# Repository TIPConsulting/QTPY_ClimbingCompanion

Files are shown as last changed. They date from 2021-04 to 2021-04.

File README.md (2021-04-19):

# QTPY Climbing Companion

Signaling device for climbers to communicate when voice commands or hand signs are not feasible.  This is a discreet helmet augmentation that adds simple radio signaling to your existing helmet.  Climbing Companion uses small touch sensors and vibrators to send left hand or right hand signals.  These can be combined to communicate arbitrary commands to your partner.  The nRF24+ radio module can reach up 100m, so you'll never have to worry about signaling again on long routes.

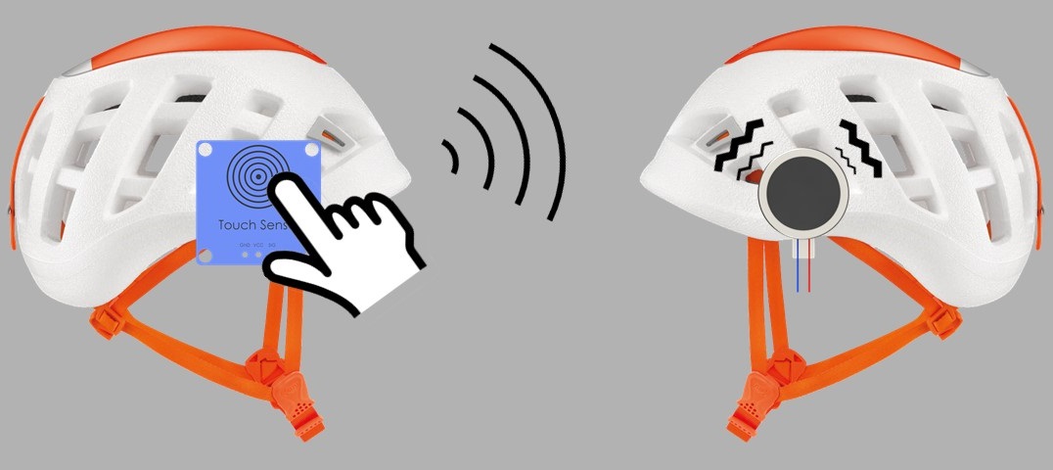
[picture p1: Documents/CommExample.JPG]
CommExample


## Inspiration

Climbing Companion is inspired by own experiences climbing across Colorado.  Its common to find yourself climbing near loud rivers or busy roads where its difficult for belayers and climbers to hear each other.  Furthermore, many routes are shaped such that partners can't see each other after the first 40ft of climbing.  When these obstacles intersect, belayers are forced to make critical safety decisions based on intuition.  Many climbers have died due to such communication failures.

Climbing Companion provides a stable platform for partners to signal each other when primary methods are unreliable.  Some climbers elect to carry 2-way hand radios, but these can be bulky and present a new safety risk if they are dropped or they could injure the climber during a fall.  Climbing Companion opts for a more streamlined approach than conventional radios.  By only supporting a small set of signaling features, we are able to squeeze our hardware into a tiny package and integrate it directly into a helmet.  This means that the device is also right where it needs to be - it won't shift around, it won't fall off a harness, and it won't get in your way.

The goal is not to replace all voice commands or hand signals, but rather supplement them during safety critical operations like setting anchors or cleaning routes.  The following image shows a scenario in which Climbing Companion would be ideal - the belayer is not visible and a fast river drowns out any voice commands.  Our radio module would allow the climber to signal when he sets his anchor or needs a rest.

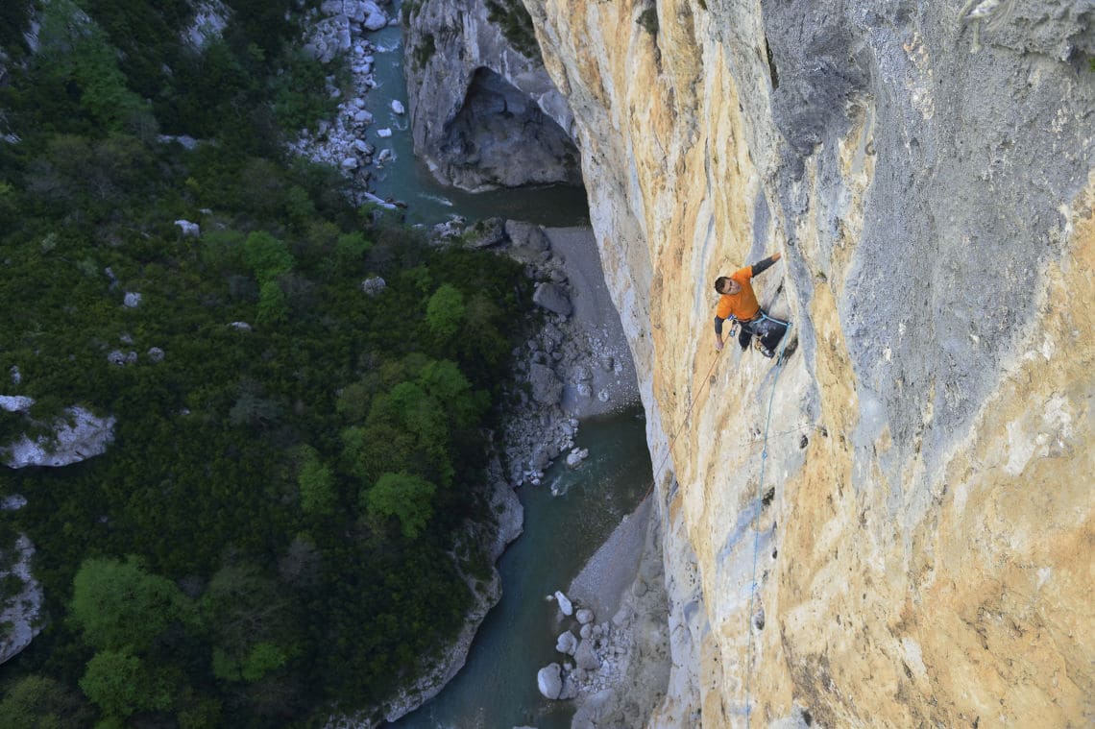
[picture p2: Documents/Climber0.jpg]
Climber


## Hardware

- 2x [QT Py Microcontroller](https://www.adafruit.com/product/4600)
- 2x [RF24 Radio Modules](https://www.amazon.com/Makerfire-Arduino-NRF24L01-Wireless-Transceiver/dp/B00O9O868G)
- 2x 150mAH Lipo Battery
- 2x Slide Switch
- 4x [Vibrator Disc](https://www.amazon.com/tatoko-12000RPM-Wired-Phone-Vibration/dp/B07L5V5GYG/)
- 4x Touch Sensor / Conductive Strips

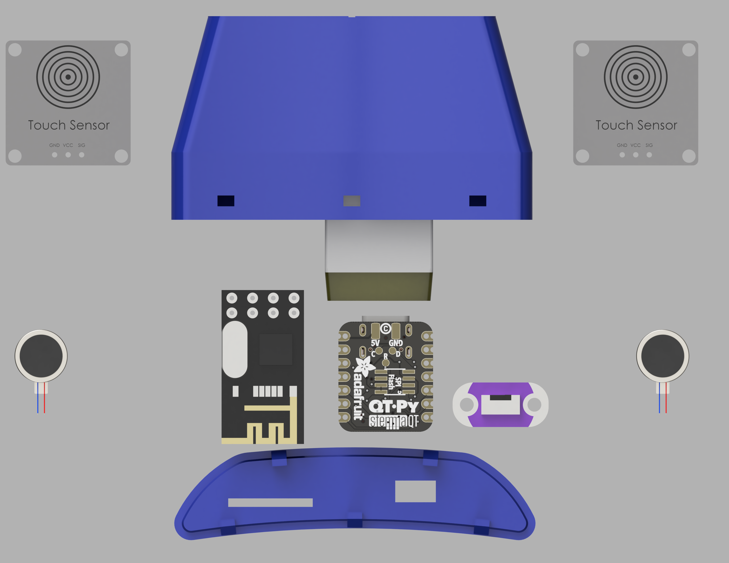
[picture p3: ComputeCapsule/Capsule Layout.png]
Component Layout


## Design

From the very outset, we knew that Climbing Companion would have to prioritize form factor and energy use over features.  We chose small, low power components to meet the functional requirements and nothing more.  That allows us pack our device into a tiny case - its so small that it can fit it a helmet vent!  Small parts also means low weight; the compute capsule _weighs 24g_, that's less than a locking carabiner!  You won't even notice that it's there unless your partner is signaling to you.  And our long battery life means that your partner can signal all day long, no matter how early you hit the crag.

We designed and printed an enclosure for a hemlet we have on-hand, but similar cases could be made a varity of helmets, allowing Climbing Companion to seamlessly integrate with your existing gear.

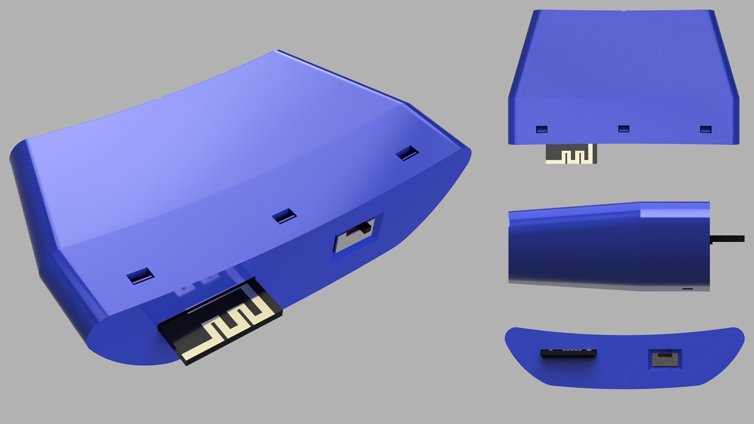
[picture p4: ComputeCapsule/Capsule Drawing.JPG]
Capsule Render


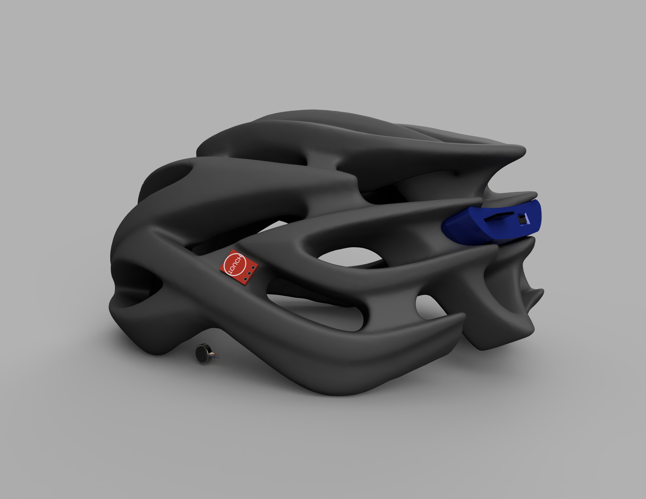
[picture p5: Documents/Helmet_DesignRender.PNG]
Helmet Render


## Build Process

Component Explosion

Helmet Explosion

### [3D STL Viewer](https://a360.co/2RFK8qV)

### Electronics

The electronics are not terribly difficult to assemble. Simply follow the standard nRF24+ wiring diagram to connect the RF module to the QT Py controller.  The connecting wires should be short so the devices can be compacted together in the case.  After connected the RF, attach leads to the QT Py for the vibrators and touch sensors.  These will need to be longer so they can extend outside of the case.  Finish off by adding a battery connector and power switch.

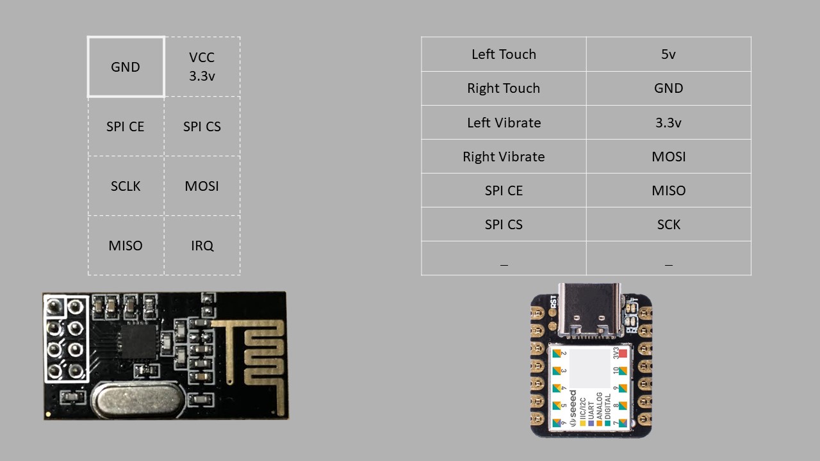
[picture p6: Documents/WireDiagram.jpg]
Wire Diagram
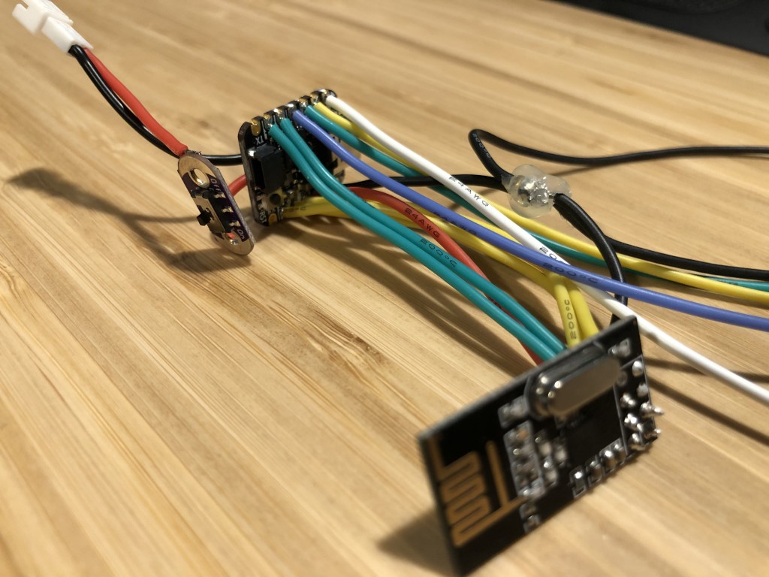
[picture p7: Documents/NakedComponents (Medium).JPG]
Electronics
 

### Compute Capsule

For the best integration possible, each compute capsule is designed to fit a specific helmet and vent.  It is critical to get a capsule that perfectly fits the helmet vent and provides enough room for the components.  It took half a dozen prototypes before we were satisfied with the fit and finish of our capsule.

### Compute Capsule Assembly

Once the components are soldered together and the case fit is perfected, the electronics will need to be inserted into the case.  We designed holes into the back of our capsule to allow vibrator and sensor wires to pass through unobtrusively.  We passed these wires through the shell first and used them to gently pull everything into place.  Only after this step should the final components be added.  If you were to add the vibrators and sensors too early, you would not be able to properly assemble the device.

1. Assemble the electronics into the compute capsule.  Do not seal the capsule yet

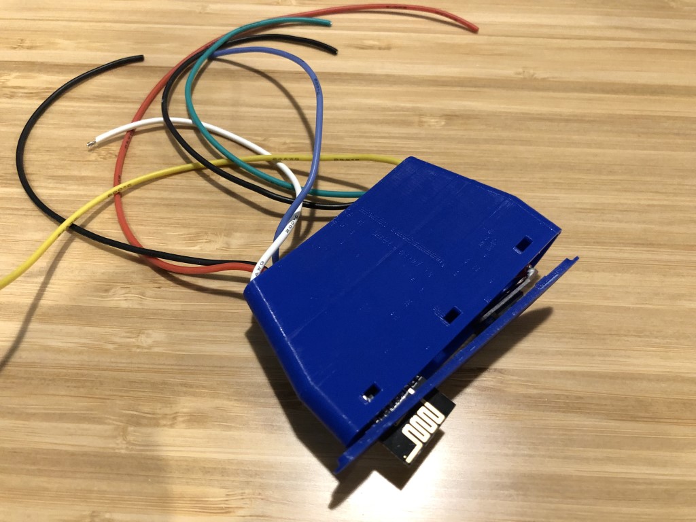
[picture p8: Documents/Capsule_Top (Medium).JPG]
Compute Capsule Top
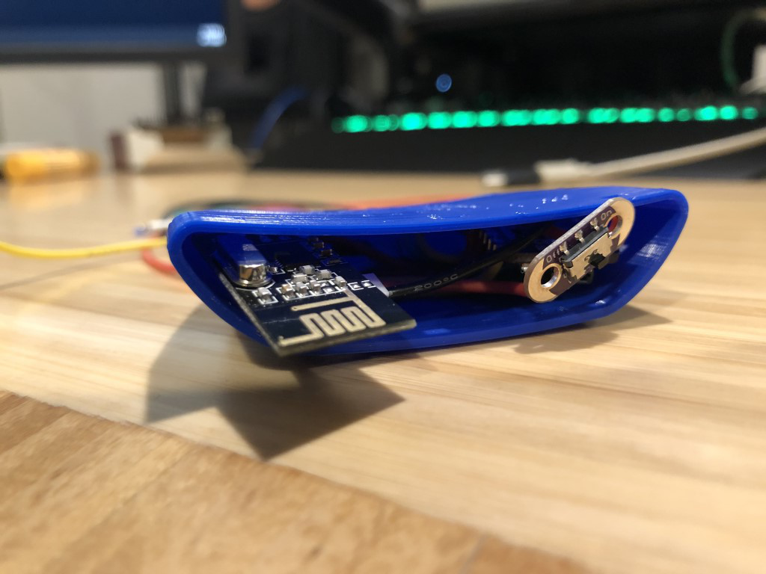
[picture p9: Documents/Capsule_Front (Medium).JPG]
Compute Capsule Front
 

2. Somewhere around this point, you should test the device to make sure it works as expected

https://user-images.githubusercontent.com/17582002/115144197-941c5780-a008-11eb-9403-8b1d7c4a9896.mp4

3. If everything works so far, add the final components to the externally breached wires.  You should solder on the vibrators and touch controls, but still do not seal the capsule yet.  We may need access later for debugging.
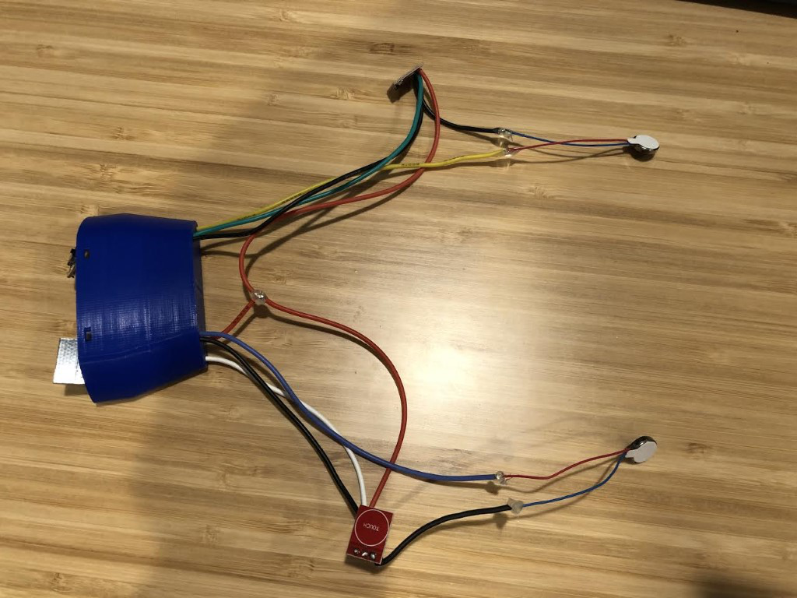
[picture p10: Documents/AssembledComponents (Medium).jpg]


### Helmet Integration

Now that the compute capsule is assembled, we can add integrate it into our helmet.  Align the compute capsule with the back of the helmet in the proper vent slot.  Insert the wires through the vent first and gently pull them from the inside as you guide the capsule into position.  Once fully seated, the compute capsule should wedge into position - the friction alone is enough to keep it in place.  Now route the touch pads and vibration modules to their respective locations and affix them using your preferred adhesive.

Make sure that all of the components are secure and the wires are well routed.  Now add the battery to the compute capsule.  Give it another test to make sure everything still works.  Especially check that the touch pads and vibrators work properly since those haven't been tested yet.  If everything looks good, then seal the capsule!

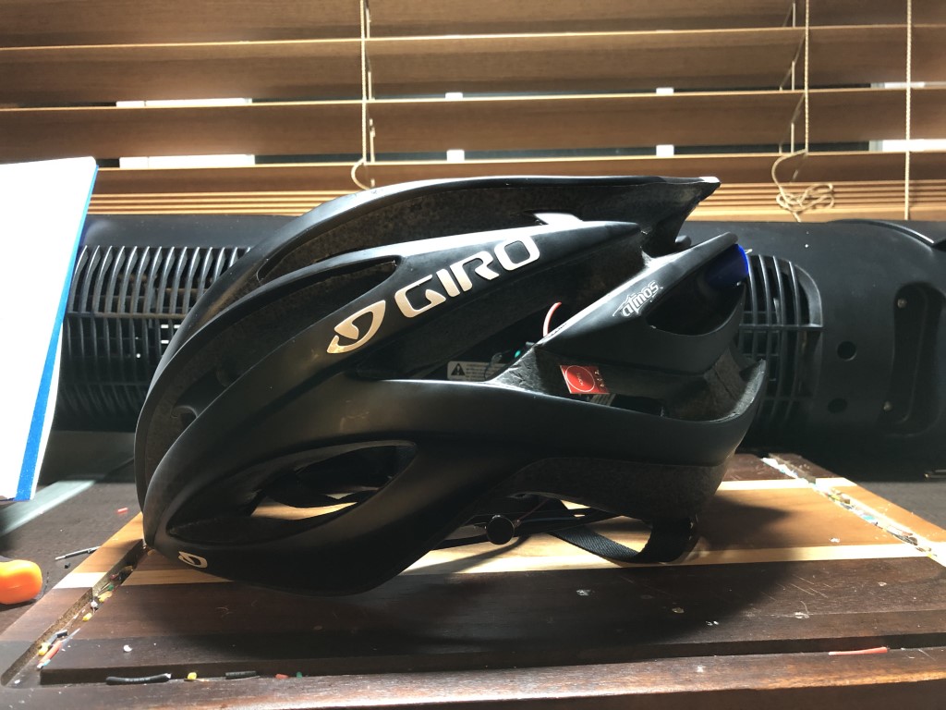
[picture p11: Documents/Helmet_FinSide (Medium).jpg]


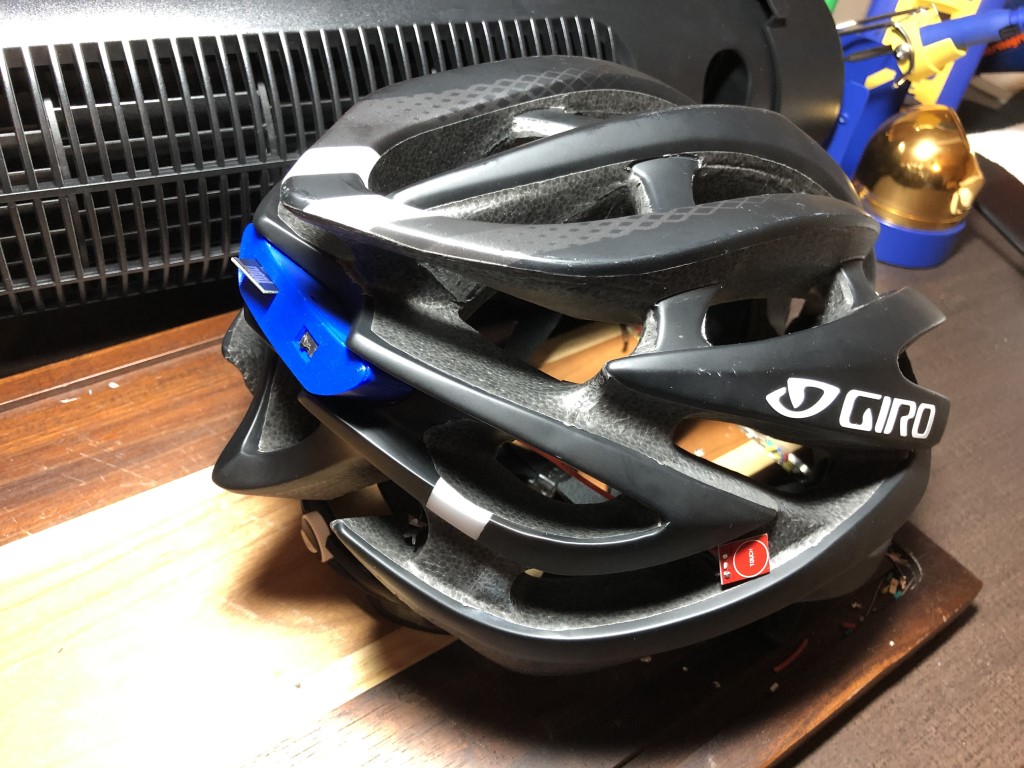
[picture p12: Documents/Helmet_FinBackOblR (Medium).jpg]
Helmet Side
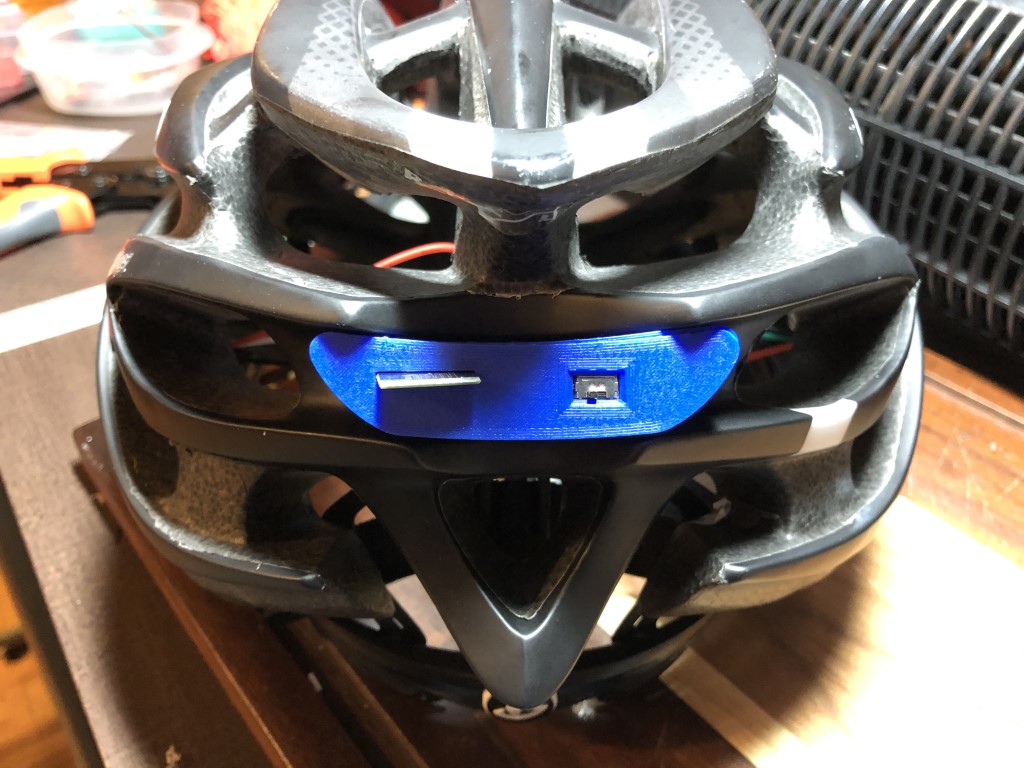
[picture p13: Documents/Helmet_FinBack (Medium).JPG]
Helmet Back
 

https://user-images.githubusercontent.com/17582002/115144217-b910ca80-a008-11eb-8e25-dc47edc94432.mp4

## Final Testing

Testing was a remarkable success.  The helmet fits well, the wires tuck out of the way easily and you don't even notice that they are there.  And of course, it operates admirably as well.  When triggered, the vibrators actuate and the wearer can easily identify the side and duration.  The vibrators we used work very well; they're strong enough to feel, but not so strong to cause a headache.  We tested the radio up to roughly 100m and had no loss of quality at that range.  We left 2 helmets running and found that their batteries lasted almost 10 hours, perfect for a day trip to the crag.

Here are 2 benchtop demo videos.  In them you can see 2 helmets interacting.  It is difficult to see since vibrator is subtle, but if you turn up your volume you can hear the motors trigger when the transmit button is pressed.

https://user-images.githubusercontent.com/17582002/115144228-c7f77d00-a008-11eb-94d9-e0d80b0c8686.mp4

https://user-images.githubusercontent.com/17582002/115144231-ccbc3100-a008-11eb-89ab-705404f198c9.mp4

## Conclusions

Climbing Companion is the perfect tool for maintaing contact with your climbing partner.  It allows partners to signal each when normal methods fail and its integrated form factor makes it far safer than carrying a radio.

# [Final Video](https://www.youtube.com/watch?v=6wvUFTiohLA)

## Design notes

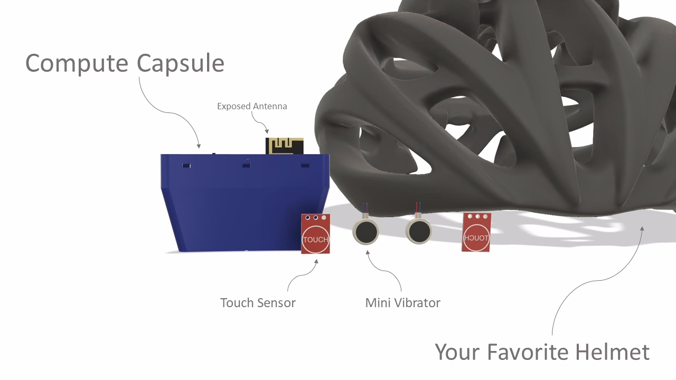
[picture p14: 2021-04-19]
Documents/helmetHardware.bmp

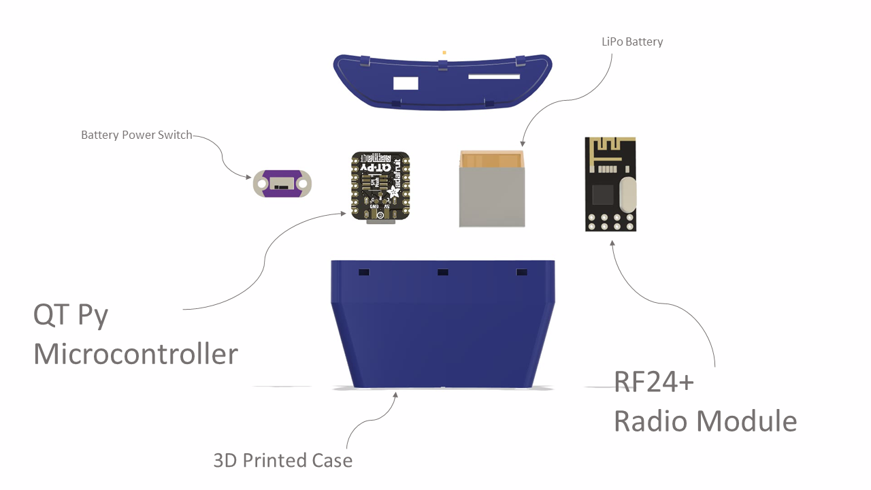
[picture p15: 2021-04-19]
Documents/computeHardware.bmp

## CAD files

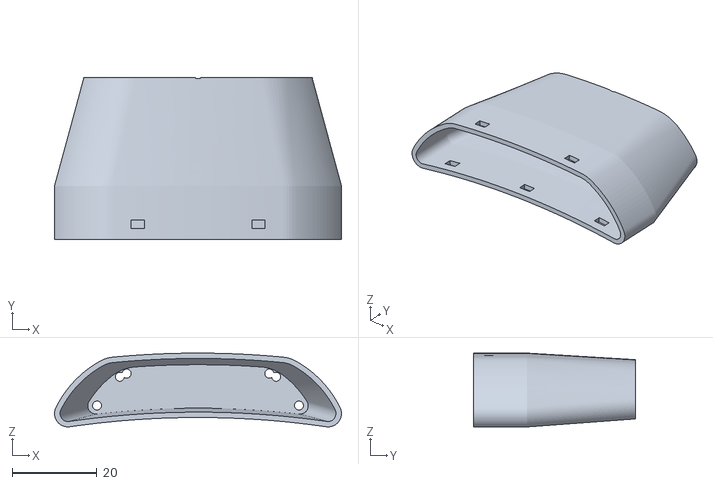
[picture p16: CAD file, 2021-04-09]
ComputeCapsule/Helmet Transmitter Case Redux v14.stl
67.9 x 38.3 x 17.5

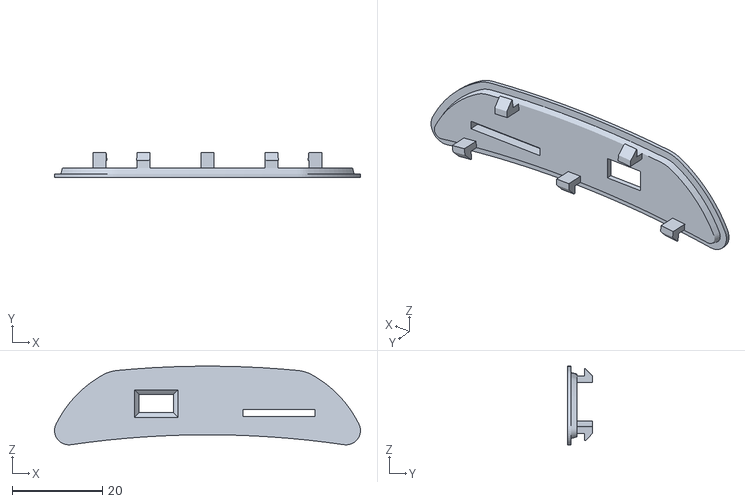
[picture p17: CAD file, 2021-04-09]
ComputeCapsule/Helmet Transmitter Lid Redux v8.stl
67.9 x 5.46 x 17.5

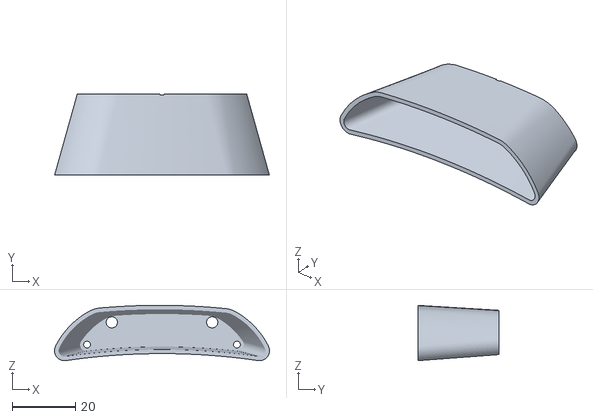
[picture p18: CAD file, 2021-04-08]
ComputeCapsule/Helmet Transmitter Case v4.stl
67.8 x 25.7 x 17.5

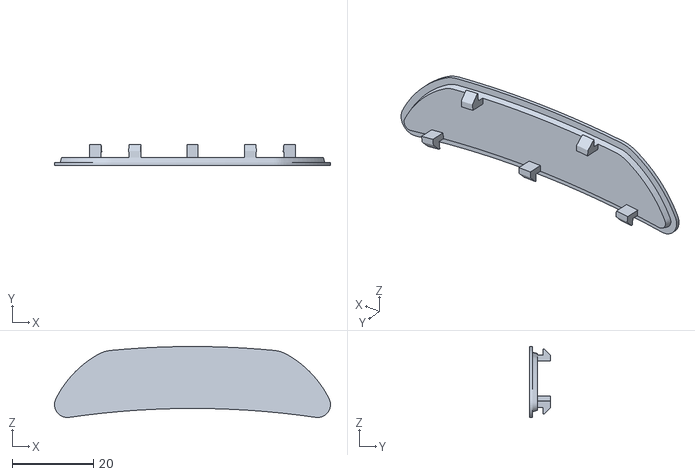
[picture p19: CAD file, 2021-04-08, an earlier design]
ComputeCapsule/Helmet Transmitter Lid Redux v1.stl
67.9 x 5.23 x 17.5

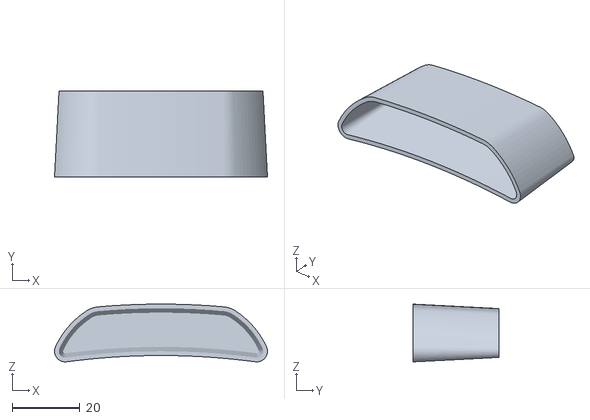
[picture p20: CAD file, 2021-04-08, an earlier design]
ComputeCapsule/Helmet Transmitter Case v2.stl
63.1 x 25.4 x 17.1

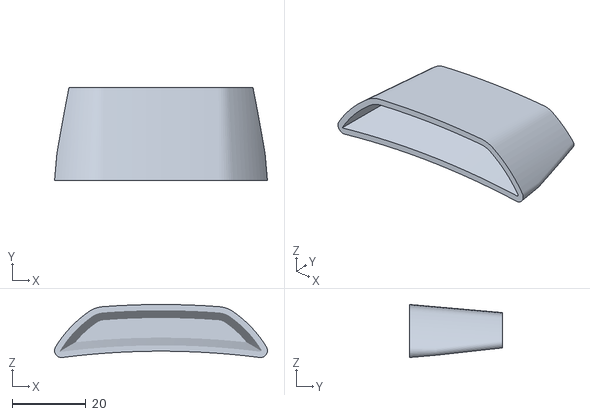
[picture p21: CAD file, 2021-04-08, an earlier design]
ComputeCapsule/Helmet Transmitter Case v1.stl
57.9 x 25.4 x 14.4

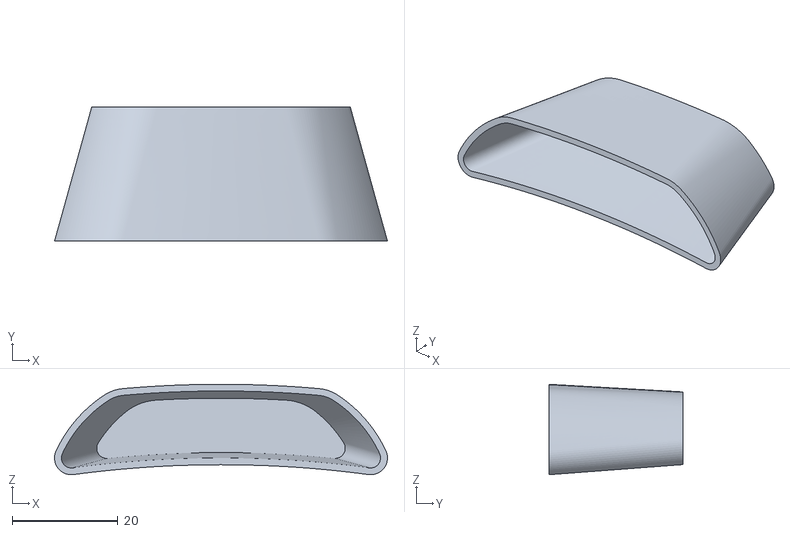
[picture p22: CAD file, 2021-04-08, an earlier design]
ComputeCapsule/Helmet Transmitter Case v3.stl
63.1 x 25.4 x 17.1

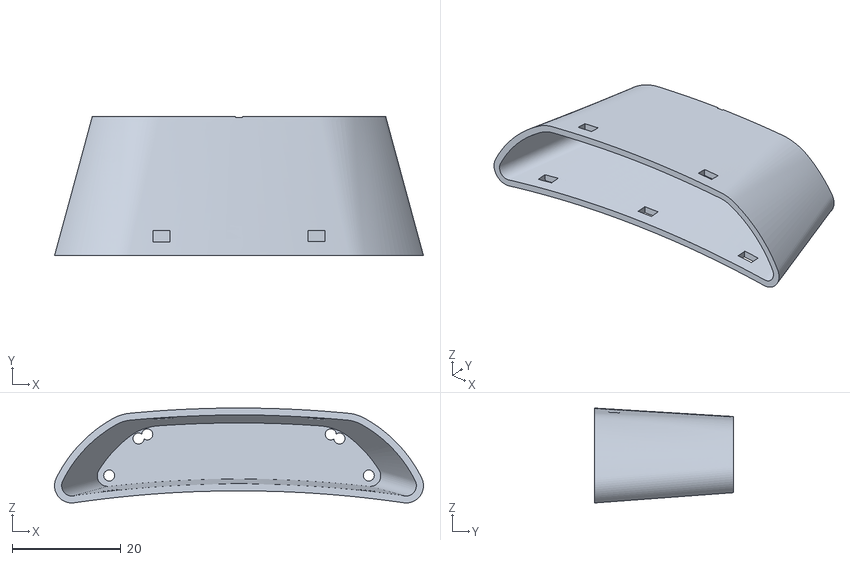
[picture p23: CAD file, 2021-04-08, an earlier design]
ComputeCapsule/Helmet Transmitter Case Redux v4.stl
67.9 x 25.6 x 17.5

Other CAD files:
ComputeCapsule/Helmet Transmitter Lid Redux v2.stl
ComputeCapsule/Helmet Transmitter Lid Redux v4.stl

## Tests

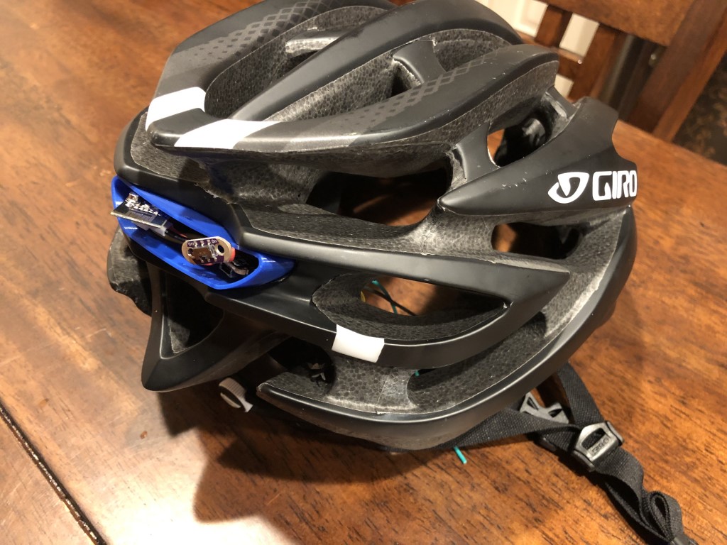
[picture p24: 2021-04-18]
Documents/Helmet_TestBack (Medium).JPG

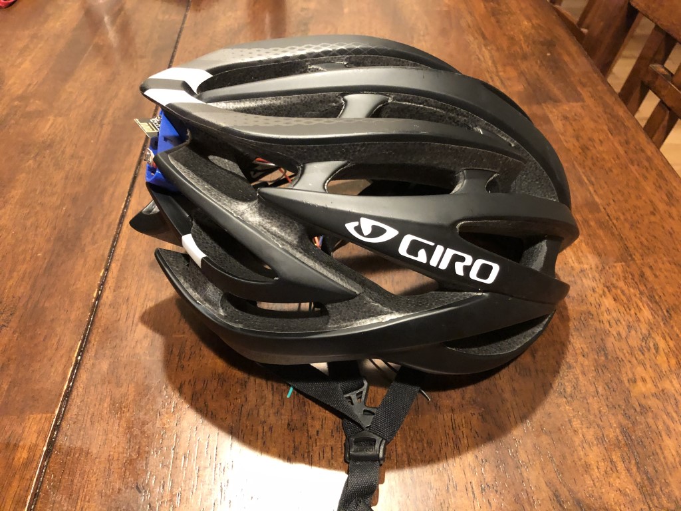
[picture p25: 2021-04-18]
Documents/Helmet_TestSide (Medium).JPG

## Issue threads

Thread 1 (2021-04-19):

Concerns for Product Realization

TIPConsulting, 2021-04-19:
While this device works, it's not ready for use in the wild. Since the helmet would perform safety critical functions, it needs to be more robust and it requires extensive test validation.

Current concerns
- Compute capsule needs to be remodeled for climbing helmets
- Device needs a bigger battery to last longer
- Activation buttons must be fine tuned to avoid accidental triggers
- Buttons should be in a location where a single hand can trigger both sides.
- The antenna should integrated directly into the capsule. The current exposed antenna is too liable to break
- Cross-y'all mitigation. Ensure that neighboring climbers are not in the same channel
- The devices need hot-pairing. Partners change through the day and they will need to pair to each other quickly and easily
- The devices will either need to be extremely durable or cheap and and easily replaceable. Possibly give coupons so the second+ is cheaper?
- Provide guidance on simple command semantics for new users

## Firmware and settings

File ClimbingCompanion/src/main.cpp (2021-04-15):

#include <Arduino.h>
#include <SPI.h>
#include <RF24.h>
#include <Adafruit_FreeTouch.h>
#ifdef NEOPIX
#include <Adafruit_NeoPixel.h>
#endif

#ifdef NEOPIX
Adafruit_NeoPixel neoStrip(1, NEOPIX, NEO_GRB + NEO_KHZ800);
#endif

/****************** User Config ***************************/
/***      Set this radio as radio number 0 or 1         ***/
bool radioNumber = RADIO_NUM;

//TODO: set pins
/* Hardware configuration: Set up nRF24L01 radio on SPI bus plus pins 7 & 8 */
RF24 radio(RADIO_PORT_CE, RADIO_PORT_CS);

/**********************************************************/
byte addresses[][6] = {"1Node", "2Node"};
// Used to control whether this node is sending or receiving
bool role = 0;
bool isTransmitting = false;
constexpr int lastReceiptThresh = 200;
unsigned long lastReceipt = 0;

inline bool CheckTouchLeft();
inline bool CheckTouchRight();
void SendRF(bool, bool);
void ListenRF();
void SetLightState(bool);

void setup()
{
  Serial.begin(115200);
  Serial.println(F("RF24/examples/GettingStarted"));
  Serial.println(F("*** PRESS 'T' to begin transmitting to the other node"));

  pinMode(LED_BUILTIN, OUTPUT);
  pinMode(TOUCH_LEFT, INPUT);
  pinMode(TOUCH_RIGHT, INPUT);
  pinMode(VIBE_LEFT, OUTPUT);
  pinMode(VIBE_RIGHT, OUTPUT);
  digitalWrite(VIBE_LEFT, 0);
  digitalWrite(VIBE_RIGHT, 0);
#ifdef NEOPIX

  neoStrip.begin();
  neoStrip.setBrightness(150);
  neoStrip.show(); // Initialize all pixels to 'off'
#endif
#ifdef NEOPIX_QUIET
  digitalWrite(NEOPIX_QUIET, 0);
#endif

  radio.begin();

  // Set the PA Level low to prevent power supply related issues since this is a
  // getting_started sketch, and the likelihood of close proximity of the devices. RF24_PA_MAX is default.
  radio.setPALevel(RF24_PA_MAX);

  // Open a writing and reading pipe on each radio, with opposite addresses
  if (radioNumber)
  {
    radio.openWritingPipe(addresses[1]);
    radio.openReadingPipe(1, addresses[0]);
  }
  else
  {
    radio.openWritingPipe(addresses[0]);
    radio.openReadingPipe(1, addresses[1]);
  }

  // Start the radio listening for data
  radio.startListening();
}

void loop()
{
  /****************** Change Roles via Touch Commands ***************************/

  bool sendLeft = false, sendRight = false;

  sendLeft = CheckTouchLeft();
  sendRight = CheckTouchRight();

  role = sendLeft | sendRight;
  if (!isTransmitting && role)
  {
    radio.stopListening(); // First, stop listening so we can talk.
    isTransmitting = true;
  }
  else if (isTransmitting && !role)
  {
    SendRF(0, 0);
    radio.startListening(); // restart listener
    isTransmitting = false;
  }

  /****************** Ping Out Role ***************************/
  if (role == 1)
  {
    SendRF(sendLeft, sendRight);
  }

  /****************** Pong Back Role ***************************/
  if (role == 0)
  {
    ListenRF();
  }
}

bool CheckTouchLeft()
{
  bool x = (digitalRead(TOUCH_LEFT) == 1);
  if (x)
    Serial.println("left");
  return x;
}

bool CheckTouchRight()
{
  bool x = (digitalRead(TOUCH_RIGHT) == 1);
  if (x)
    Serial.println("right");
  return x;
}

void SendRF(bool sendLeft, bool sendRight)
{
  Serial.print(F("Sending - ["));
  Serial.print(sendLeft);
  Serial.print(F(", "));
  Serial.print(sendRight);
  Serial.print(F("]"));

  byte sendBuffer = (sendLeft * 0xF0) | (sendRight * 0x0F);

  Serial.println(sendBuffer, BIN);

  if (!radio.write(&sendBuffer, sizeof(byte)))
  {
    Serial.println(F("failed"));
  }
  delay(100);
}

void ListenRF()
{
  byte recvBuffer = 0;
  bool leftMotorOn = 0, rightMotorOn = 0;

  if (radio.available())
  {
    // Variable for the received timestamp
    while (radio.available())
    {                                        // While there is data ready
      radio.read(&recvBuffer, sizeof(byte)); // Get the payload
    }

    Serial.print(F("Receive - "));
    Serial.println(recvBuffer, BIN);

    leftMotorOn = ((recvBuffer & 0xF0) == 0xF0);
    rightMotorOn = ((recvBuffer & 0x0F) == 0x0F);

    analogWrite(VIBE_LEFT, leftMotorOn * 256);
    analogWrite(VIBE_RIGHT, rightMotorOn * 256);
    SetLightState(leftMotorOn | rightMotorOn);
    lastReceipt = millis();
  }

  if ((millis() - lastReceipt) > lastReceiptThresh)
  {
    digitalWrite(VIBE_LEFT, 0);
    digitalWrite(VIBE_RIGHT, 0);
    SetLightState(0);
  }
}

void SetLightState(bool isOn)
{
  digitalWrite(LED_BUILTIN, isOn);
#ifdef NEOPIX
  if (isOn)
  {
    neoStrip.setPixelColor(0, 255, 0, 0);
  }
  else
  {
    neoStrip.clear();
  }
  neoStrip.show();
#endif
}

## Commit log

2021-04-08 Init commit
    [Helmet Transmitter Case Redux v4.stl, Helmet Transmitter Case v1.stl, Helmet Transmitter Case v2.stl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]
2021-04-09 Update compute capsule
    [Helmet Transmitter Case Redux v14.stl, Helmet Transmitter Lid Redux v8.stl]
2021-04-15 fix motors
2021-04-18 Add new assembly pics
